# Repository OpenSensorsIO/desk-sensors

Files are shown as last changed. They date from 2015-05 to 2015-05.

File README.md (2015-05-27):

# Desk Sensor Stuff
This repo contains the Arduino code for the RFu328 ultrasonic desk sensor as well as the Node-RED flow for the hub device and the PCB EAGLE files.

Check out localhost:1880/status for output from the sensors.

https://cloud.githubusercontent.com/assets/6317446/7678626/92cf6eda-fd4d-11e4-8980-ae222dfc567b.jpg

Big acknowledgement of Oxford Flood Network, ThingInnovations and Andrew Lesley for great examples.

PS for the EAGLE files: board v3 was designed to take 6-12V input and use two Wirelessthings PowerPods (PowerPOD 1117) to transform to 3.3V (for the RFu328) and 5V (for the HC-SR04 ultrasonic device). However, it was found that these down-regulating pods have unacceptable quiescent currents. We now use board v3 with a bridge (connecting Vin to Vout for the designated 3.3V  pod), and put a PowerPOD NCP1402 to transform incoming 3.6V from a SAFT battery to 5V.

There's a board v4 with a transistor to control the quiescent draw of either ultrasonic or PIR sensors.

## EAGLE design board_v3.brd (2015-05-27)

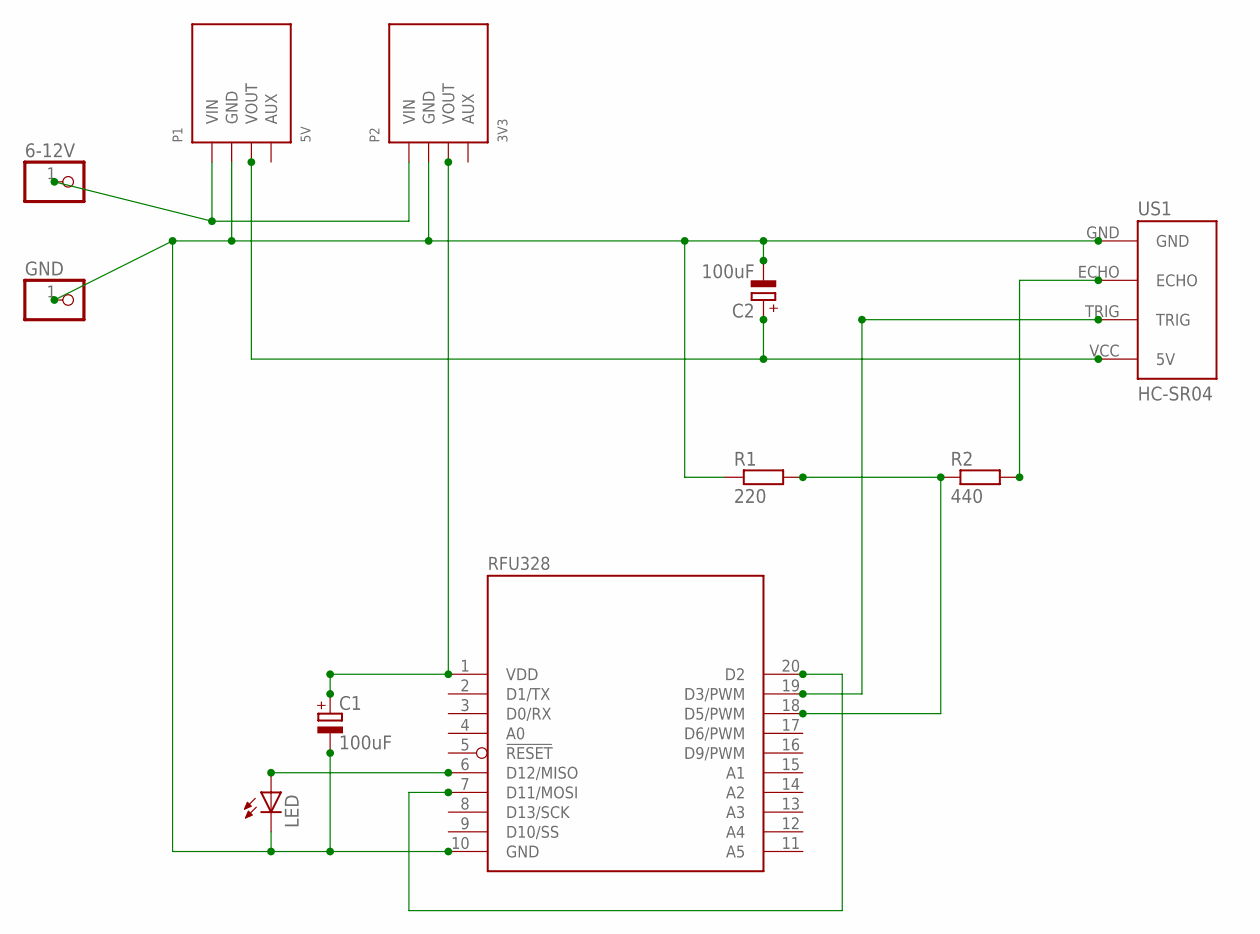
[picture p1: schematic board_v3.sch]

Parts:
6-12V: PINHD-1X1; 1X01
C1, C2: 100uF; E5-5
GND: PINHD-1X1; 1X01
LED: TLLR4400; LED3MM
P1: 5V; POWER-POD-REF
P2: 3V3; POWER-POD-REF
R1: 220; 0207/7
R2: 440; 0207/7
RFU328: RFµ-328-SOCKET-V2.0; RFµ-SOCKET-V2.0
US1: HC-SR04; HC-SR04_FOOTPRINT

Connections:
GND: C1.-, C2.-, GND.1, LED.K (C), P1.2 (GND), P2.2 (GND), R1.1, RFU328.10 (GND), US1.GND
unnamed: LED.A, RFU328.6 (D12/MISO)
unnamed: R2.2, US1.ECHO
unnamed: RFU328.7 (D11/MOSI), RFU328.20 (D2)
unnamed: C2.+, P1.3 (VOUT), US1.VCC (5V)
unnamed: R1.2, R2.1, RFU328.18 (D5/PWM)
unnamed: RFU328.19 (D3/PWM), US1.TRIG
unnamed: 6-12V.1, P1.1 (VIN), P2.1 (VIN)
VDD: C1.+, P2.3 (VOUT), RFU328.1 (VDD)

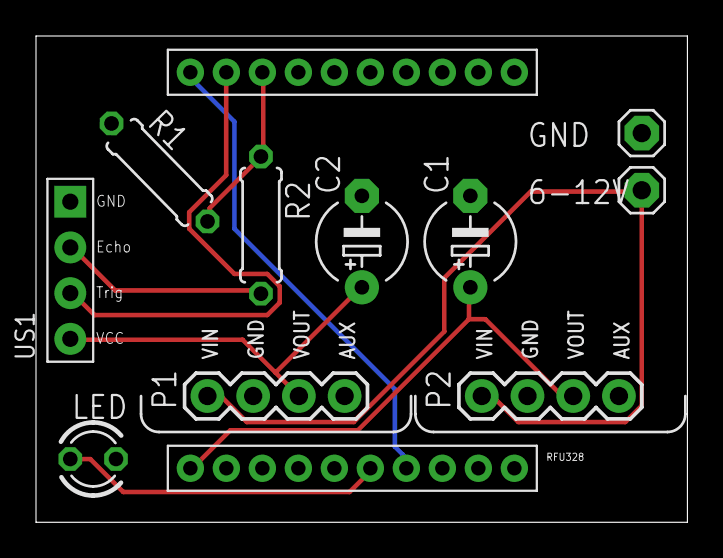
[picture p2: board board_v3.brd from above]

Board: 2 copper layers, 36.2 x 27.0 mm, 11 parts (0 on the bottom side), 9 nets.

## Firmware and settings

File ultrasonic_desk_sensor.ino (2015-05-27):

//////////////////////////////////////////////////////////////////////////////////////////////////////////
//
// ULTRASONIC ("DESK OCCUPANCY") DEVICE FIRMWARE v0.11 RELEASE
//
// (C) 2015 by Boris Adryan, badryan@gmail.com, for OpenSensors.IO
//
// Feel free to share under Apache 2 license.
//////////////////////////////////////////////////////////////////////////////////////////////////////////
//
// HC-SR04 ultrasonic sensor on Wirelessthings RFu328
//
//////////////////////////////////////////////////////////////////////////////////////////////////////////
// The RFu328 is in hardware sleep (mediated by the onboard SRF radio) and awakes periodically from
// SHORTSLEEP to take a measurement with the HC-SR04 (based on https://code.google.com/p/arduino-new-ping/).
// Every INTERATIONS_SLEEPCHECK the radio stays awake for SLEEPCHECK_TIMEOUT milliseconds and sends a
// CHECKTIME message. This is acknowledged by the remote station with a xxSLEEP message, where xx is
// the number of hours the RFu328 is going into deep sleep before going into the SHORTSLEEP iterations again
// 
// BUGFIXING PROTIP: Hardware sleep can be interrupted by shortening SRF pin 11 (lowest lateral left) to GND
// 
// RFu-328 specific AT commands (requires firmware RFu-328 V0.84 or better) -- implementation and hints from
// https://github.com/CisecoPlc/LLAPSerial/blob/master/examples/VeryLowPower_RFu328_ATSM3/).
//    The following RFu specific AT commands are supported in V0.84 or later
//		Added a new sleep mode (ATSM3) Wake after timed interval
//			The duration is specified by a new command ATSD, units are mS 
//			and the range is 32bit (max approx. 49 days)
//				e.g. ATSD5265C00 is one day (hex 5265C00 is decimal 86400000)
//				ATSD36EE80 is one hour
//				ATSD493E0 is five minutes
//		This sleep mode can be used to wake the 328 after a timed interval 
//			by connecting RFu-328 pin 7 to pin 19, D3(INT1) or 20, D2(INT0).
//		Using this technique means that a RFu-328 can sleep for a timed 
//			period consuming about 0.6uA, instead of using the AVR328 watchdog (for timing) 
//			which uses around 7uA.
//
//////////////////////////////////////////////////////////////////////////////////////////////////////////


#include <NewPing.h>
#include <LLAPSerial.h>

#define TRIGGER_PIN  3  // Arduino pin tied to trigger pin on the ultrasonic sensor.
#define ECHO_PIN     5  // Arduino pin tied to echo pin on the ultrasonic sensor.
#define RADIO_PIN    8  // pin 8 controls the radio
#define SLEEP_PIN    4  // pin 4 controls the radio sleep
#define WAKE_PIN     2  // the one that connects to pin 7/D11
#define BLINK_PIN   12  // pin 12 blinks the status LED
#define MAX_DISTANCE 300 // maximum distance we want to ping for (in centimeters). Maximum sensor distance is rated at 400-500cm.

#define ITERATIONS_SLEEPCHECK 60 // check for SLEEPCHECK_TIMEOUT ms all ITERATIONS_SLEEPCHECK iterations
#define SLEEPCHECK_TIMEOUT 1000 //

// ATSD1388 - 5 sec; ATSD4E20 - 20 sec; ATSD493E0 - 5 min; ATSDEA60 - 1 min; ATSD1B7740 - 30 min; ATSD36EE80 - 60 min
#define SHORTSLEEP "ATSDEA60"

/////////////////////////////////////////////////////////
// SRF AT command handling
/////////////////////////////////////////////////////////

uint8_t setupSRF(char* sleepString) {	// set Sleep mode 2
    if (!enterCommandMode()) {	        // if failed once then try again
	if (!enterCommandMode()) return 1;
    }     
    if (!sendCommand(sleepString)) return 2;
    if (!sendCommand("ATSM3")) return 3;
    if (!sendCommand("ATDN")) return 4;
    return 5;
}

uint8_t enterCommandMode() {
  delay(1200);
  Serial.print("+++");
  delay(500);
  while (Serial.available()) Serial.read();  // flush serial in
  delay(500);
  return checkOK(500);
}

uint8_t sendCommand(char* lpszCommand) {
  Serial.print(lpszCommand);
  Serial.write('\r');
  return checkOK(100);
}

uint8_t checkOK(int timeout) {
  uint32_t time = millis();
    while (millis() - time < timeout) {
        if (Serial.available() >= 3) {
            if (Serial.read() != 'O') continue;
            if (Serial.read() != 'K') continue;
            if (Serial.read() != '\r') continue;
          return 1;
        }
    }
  return 0;
}

//////////////////////////////////////////
// HIGHER ORDER SLEEP PROCDURES
//////////////////////////////////////////
uint8_t trysleep(char* sleepString) {
  uint8_t val = 0;
    while ((val = setupSRF(sleepString)) != 5) {
      LLAP.sendInt("ERR",val); // Diagnostic
      delay(5000);	// try again in 5 seconds
    }
  return val;  
}

uint8_t checklongsleep() {
  LLAP.sendMessage("CHECKTIME");
  
  char r[7] = {' ',' ',' ',' ',' ',' ',' '};
  uint32_t time = millis();
    while (millis() - time < SLEEPCHECK_TIMEOUT) {
        if (Serial.available()) {
          int i = 0;  
            while (i < 6) {
              r[i] = r[i+1];
              i++;
            }
          r[6] = Serial.read();
        }
            
        if (r[2] == 'S' && r[3] == 'L' && r[4] == 'E' && r[5] == 'E' && r[6] == 'P') {
          // r[0]+r[1] to contain hours to sleep
          unsigned long hours = (r[0]-48)*10+r[1]-48; // r contains the ASCII value, so -48 returns the actual number value. r[0] first digit, r[1] second digit
          LLAP.sendInt("ACKDOWN", hours);
          String sleepHex = "ATSD"+String(hours * 60 * 60 * 1000, HEX); // delivers the HEX value of milliseconds to sleep and does the type conversion to char
          int str_len = sleepHex.length() + 1; 
          char ATSDcharString[str_len];
          sleepHex.toCharArray(ATSDcharString, str_len);
              
          trysleep(ATSDcharString);
          pinMode(SLEEP_PIN, INPUT);     // sleep the radio
          LLAP.sleep(WAKE_PIN, RISING, false);  // sleep until woken
          pinMode(SLEEP_PIN, OUTPUT);    // wake the radio
              
          trysleep(SHORTSLEEP);
        }        
    }
}

/////////////////////////////////////////
// SETUP OF DEVICE AND LOOP
/////////////////////////////////////////

NewPing sonar(TRIGGER_PIN, ECHO_PIN, MAX_DISTANCE); // NewPing setup of pins and maximum distance.
long iterationsAwake = 0;

void setup() {
  Serial.begin(115200); // Open serial monitor at 115200 baud to see ping results.
  
  //// generate a random name (device ID), here: a pseudo-hexadecimal value
  char a[22] = {'0','1', '2', '3', '4', '5', '6', '7', '8','9','A','B', 'C', 'D', 'E', 'F', 'G', 'H', 'I', 'J', 'K', 'L'};
  char devID[2];
  randomSeed(analogRead(11));
  devID[0] = a[random(0, 22)];
  devID[1] = a[random(0, 22)];
  
  LLAP.init(devID);
  
  ///// init the hardware
  pinMode(BLINK_PIN, OUTPUT);
  digitalWrite(BLINK_PIN, LOW);
  pinMode(RADIO_PIN, OUTPUT);    // initialize pin 8 to control the radio
  digitalWrite(RADIO_PIN, HIGH); // select the radio
  pinMode(SLEEP_PIN, OUTPUT);    // define sleep pin
  digitalWrite(SLEEP_PIN, LOW);  // wake the radio
  
  delay(400);
  
  ////// tell the world you're alive
  uint8_t val = 0;
    while (val < 3) {      
      LLAP.sendMessage(F("STARTED"));  
      val++;  
    }
 
  trysleep(SHORTSLEEP);
    
}

void loop() {
  pinMode(SLEEP_PIN, INPUT);     // sleep the radio
  LLAP.sleep(WAKE_PIN, RISING, false);  // sleep until woken
  pinMode(SLEEP_PIN, OUTPUT);    // wake the radio
  
  delay(50);                      // wait 50ms after wakeup 
  unsigned int uS = sonar.ping(); // send ping, get ping time in microseconds (uS). this is just for pump-priming
  delay(50);
  uS = sonar.ping();              // that's our real ping
  
  int dist = uS / US_ROUNDTRIP_CM;
  LLAP.sendInt("CM", dist);      // send ping distance in cm
  
  digitalWrite(BLINK_PIN, HIGH); // blink briefly
  delay(100);
  digitalWrite(BLINK_PIN, LOW);
  
  iterationsAwake++;
    if (iterationsAwake == ITERATIONS_SLEEPCHECK) {
      iterationsAwake = 0;
      checklongsleep();
   }

}
